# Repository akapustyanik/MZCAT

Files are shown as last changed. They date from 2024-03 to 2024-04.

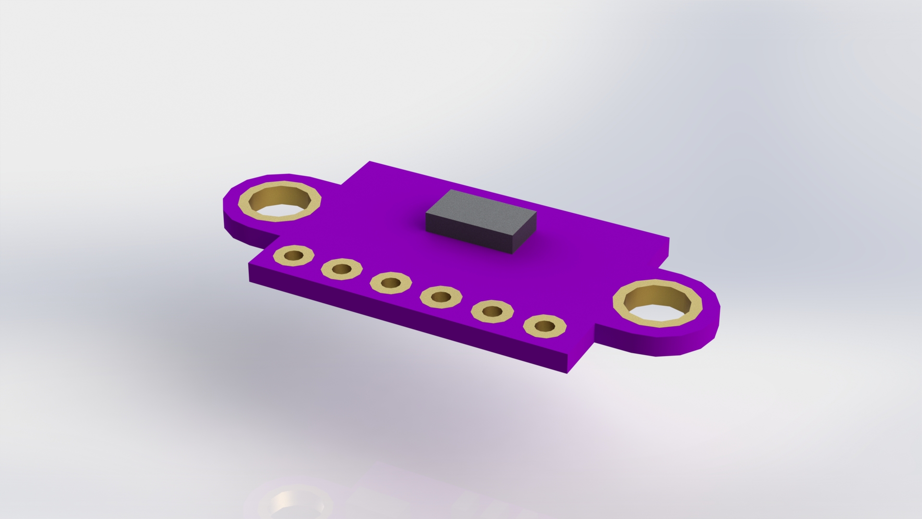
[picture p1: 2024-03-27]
Construction/other_models/vl53l0x/view 3.JPG

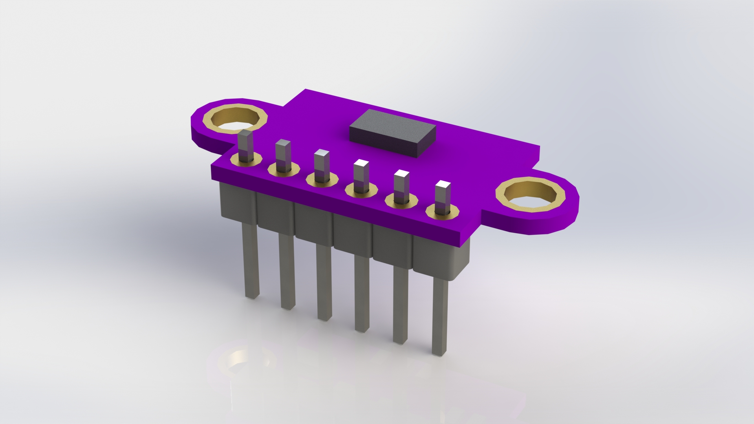
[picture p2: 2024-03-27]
Construction/other_models/vl53l0x/view 1.JPG

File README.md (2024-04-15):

  Создание роботов, находящих и спасающих людей в труднодоступных местах, является актуальной задачей современной робототехники. Роботы-спасатели крайне востребованы, поскольку не всегда есть возможность добраться до места происшествия и начать поиск пострадавших, а компактный робот, который сможет автономно найти пострадавшего и выдать нуждающемуся в помощи спасательный набор, будет полезным и сможет помочь при спасении жизней.

robot photo4

  Я участвую в соревнованиях RoboСup Rescue Maze, поэтому проект, посвящённый теме спасательных роботов актуален для меня.   
Концепцию робота можно сформулировать в трех пунктах:

1) Собственная материнская плата с двумя микроконтроллерами для распределения между ними задач: низкоуровневой - управление ходовой частью и высокоуровневой – считывание значений с датчиков, исполнения алгоритмов перемещения, нахождения кратчайшего пути и поиска пострадавших.
2) Инерциальный модуль собственной разработки с установленным на нём микроконтроллером для фильтрации и обработки данных.
3) Компактная конструкция робота с быстросъёмным механизмом крепления аккумулятора и особое устройство выдачи спасательных наборов со способом загрузки спасательных наборов подобным механизму канцелярского степлера.

В конструкции робота можно выделить основные элементы, а именно:
- Рама и защитная рама, предназначены для обеспечения жёсткости конструкции и закрепления деталей.
- Четыре мотора с уголками для крепления и дисками с шинами.
- Систему выдачи, так же служащей для крепления камер.
- Крепление аккумулятора и сама аккумуляторная сборка.

  Хотелось бы обратить особое внимание на идею создания инерциального модуля собственной разработки. Данный модуль позволит постоянно опрашивать микросхему гироскопа независимо от работы основного алгоритма на основном микроконтроллере, такая система обезопасит от потери выходных данных с датчика и позволит лучше фильтровать данные. Передача данных на основной микроконтроллер может выполняться по любому запрограммированному протоколу, что является большим преимуществом, поскольку можно написать проверку полученных данных и обезопасить алгоритм на основном микроконтроллере от неправильных значений датчика.

  Для инерциального модуля собственной разработки был создан отдельный репозиторий по ссылке - https://github.com/akapustyanik/IMU_Sensor_2023

  Также был создан YouTube канал с примерами работы робота, который можно посмотерть по ссылке - https://www.youtube.com/@mz_cat

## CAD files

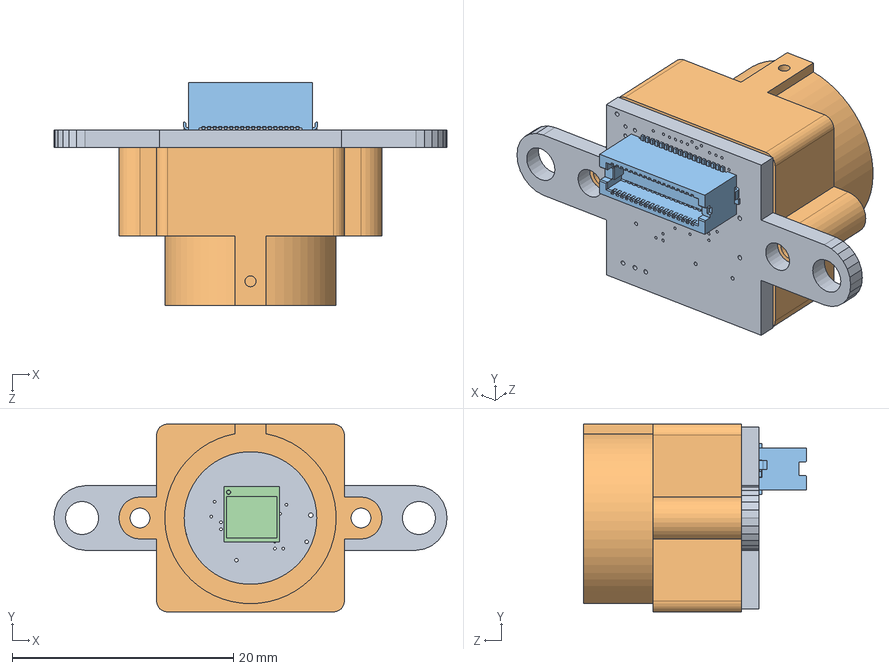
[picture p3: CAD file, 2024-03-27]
Construction/other_models/OpenMV H7/AssemblyModels/openmv4_ov7725.SLDASM
35.6 x 17.0 x 20.2 mm
ov7725
mount_lens
DF1236
CSP2-28

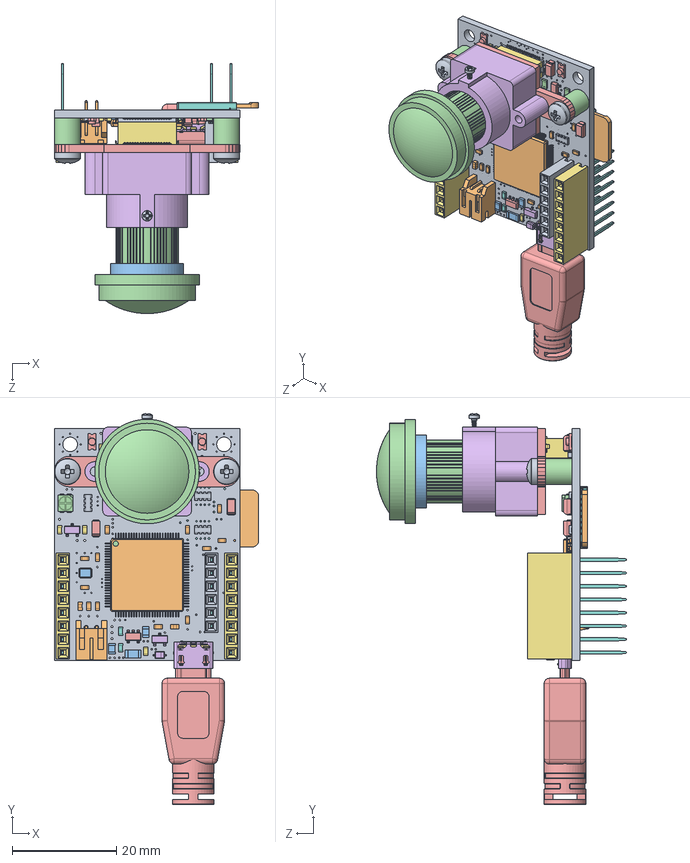
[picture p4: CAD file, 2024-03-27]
Construction/other_models/OpenMV H7/openmv4_h7.SLDASM
39.2 x 74.9 x 47.9 mm
base
C0603K_C0603K x 13
C0805K_C0805K x 2
cap3216h160 x 3
SOD323_BAT54HT1G
960240-6202-AR Body8 x 2
960240-6202-AR Pin Long x 22
960240-6202-AR Body6
Capacitor 0603 x 2
LED SMD RGB
LED 1206 IR x 2
SOT 23 x 2
Resistor 0603 x 5
R0603_SJR x 2
EXBV8V x 3
User Library-LQFP100-3_case
User Library-LQFP100-3_pin x 100
User Library-LQFP100-3_circle
SOT 23-5 x 2
UJ2-MIBH2-4-SMT_01
UJ2-MIBH2-4-SMT_02
1040310811_USD1040310811
DF12-36DS-0.5V
S2B-PH-K-S(LF)(SN)
Crystal-SM2520-4
Standoff metal 5x2.5mm x 2
ov7725
mount_lens
DF1236
CSP2-28
pan head cross recess screw_iso x 3
microsd card
LENS_Standard
LENS_Wide
Micro USB connector

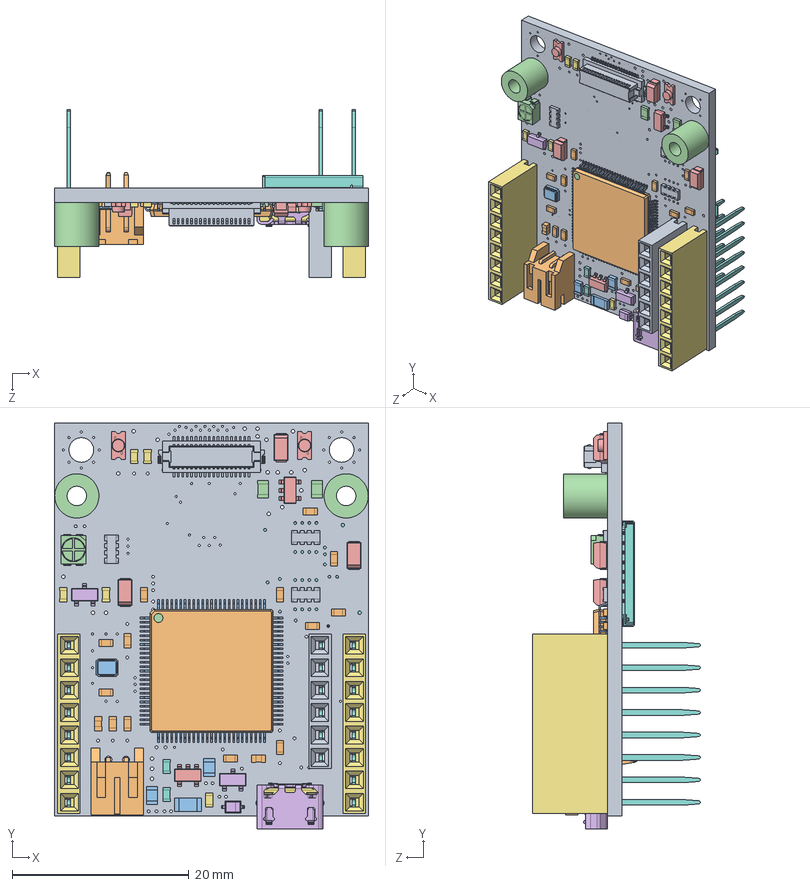
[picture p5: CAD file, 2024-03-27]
Construction/other_models/OpenMV H7/AssemblyModels/openmv4_h7_base.SLDASM
35.6 x 45.9 x 19.0 mm
base
C0603K_C0603K x 13
C0805K_C0805K x 2
cap3216h160 x 3
SOD323_BAT54HT1G
960240-6202-AR Body8 x 2
960240-6202-AR Pin Long x 22
960240-6202-AR Body6
Capacitor 0603 x 2
LED SMD RGB
LED 1206 IR x 2
SOT 23 x 2
Resistor 0603 x 5
R0603_SJR x 2
EXBV8V x 3
User Library-LQFP100-3_case
User Library-LQFP100-3_pin x 100
User Library-LQFP100-3_circle
SOT 23-5 x 2
UJ2-MIBH2-4-SMT_01
UJ2-MIBH2-4-SMT_02
1040310811_USD1040310811
DF12-36DS-0.5V
S2B-PH-K-S(LF)(SN)
Crystal-SM2520-4
Standoff metal 5x2.5mm x 2

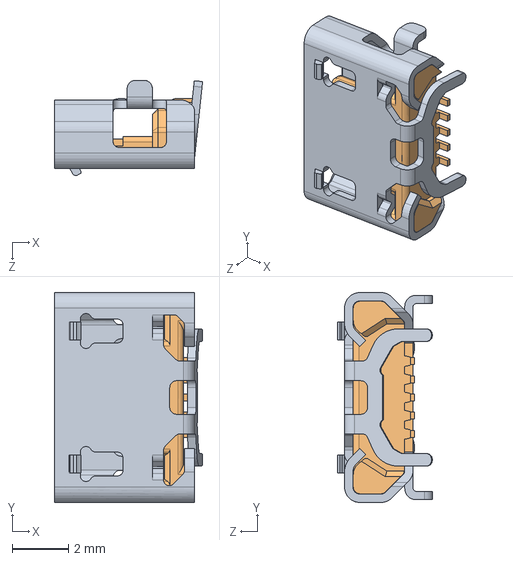
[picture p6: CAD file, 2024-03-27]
Construction/other_models/OpenMV H7/Components/Micro USB socket/UJ2-MIBH2-4-SMT.SLDASM
5.29 x 7.50 x 3.41 mm
UJ2-MIBH2-4-SMT_01
UJ2-MIBH2-4-SMT_02

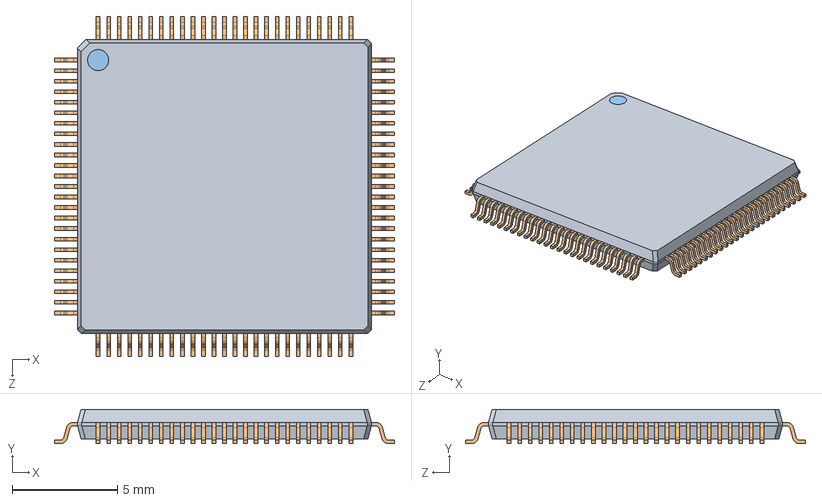
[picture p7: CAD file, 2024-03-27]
Construction/other_models/OpenMV H7/Components/LQFP100/User Library-LQFP100-3.sldasm
16.1 x 1.63 x 16.1 mm
User Library-LQFP100-3_case
User Library-LQFP100-3_pin x 100
User Library-LQFP100-3_circle

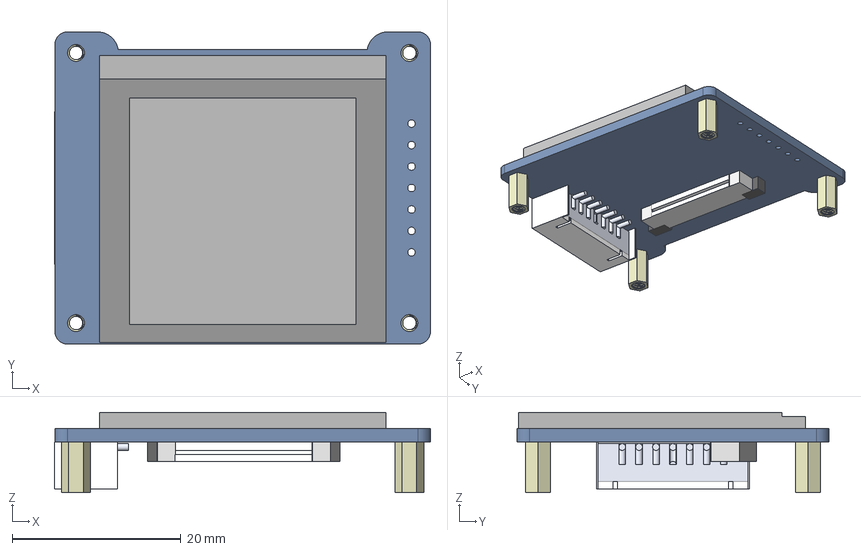
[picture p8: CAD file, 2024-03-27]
Construction/step/1_5inch-rgb-oled-module_asm-1110.stp
44.5 x 37.0 x 9.50 mm
1_5INCH-RGB-OLED
1_5INCH_OLED_RGB_PCBA
M2XH6_COPPER-POST x 4

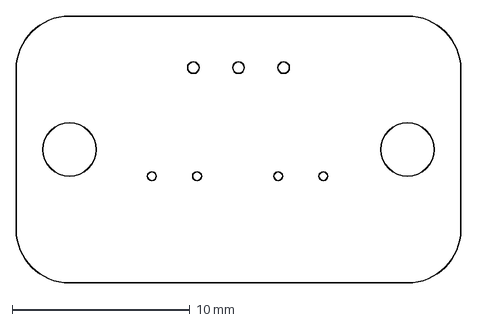
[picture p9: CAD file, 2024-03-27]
Construction/dxf/osvesh.dxf
25.0 x 15.0 mm

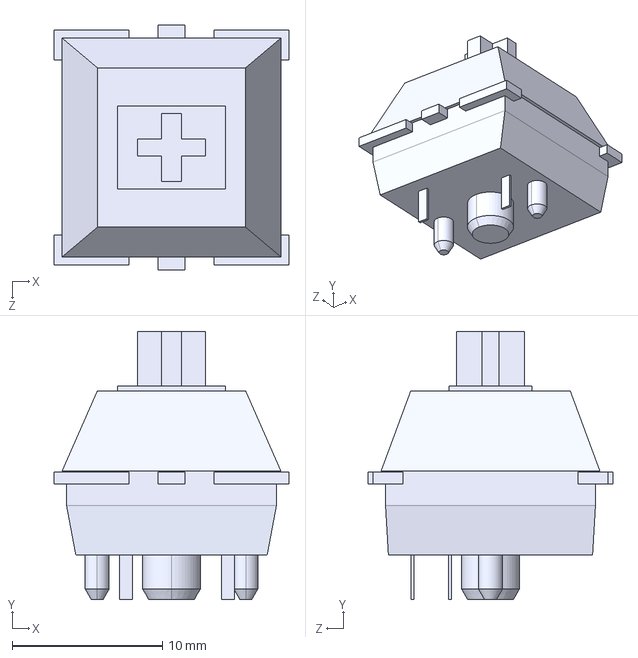
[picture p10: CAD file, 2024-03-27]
Construction/other_models/cherrry red/cherry mx.STEP
15.6 x 17.9 x 16.3 mm

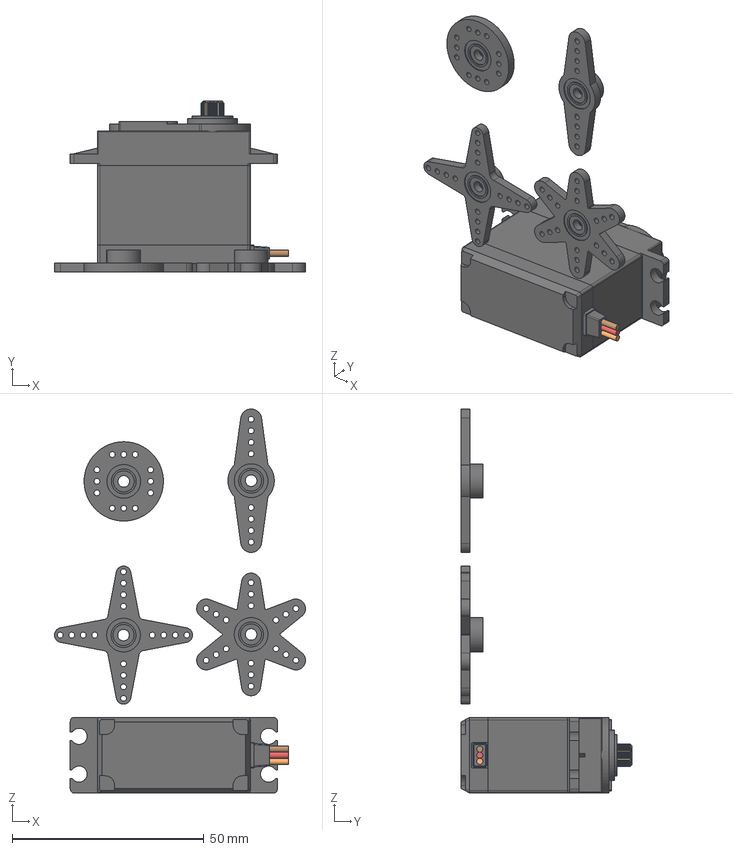
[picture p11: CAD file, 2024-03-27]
Construction/other_models/MG996R/Servo Motor MG996R_ 一字摇臂.step
65.4 x 44.5 x 100.1 mm

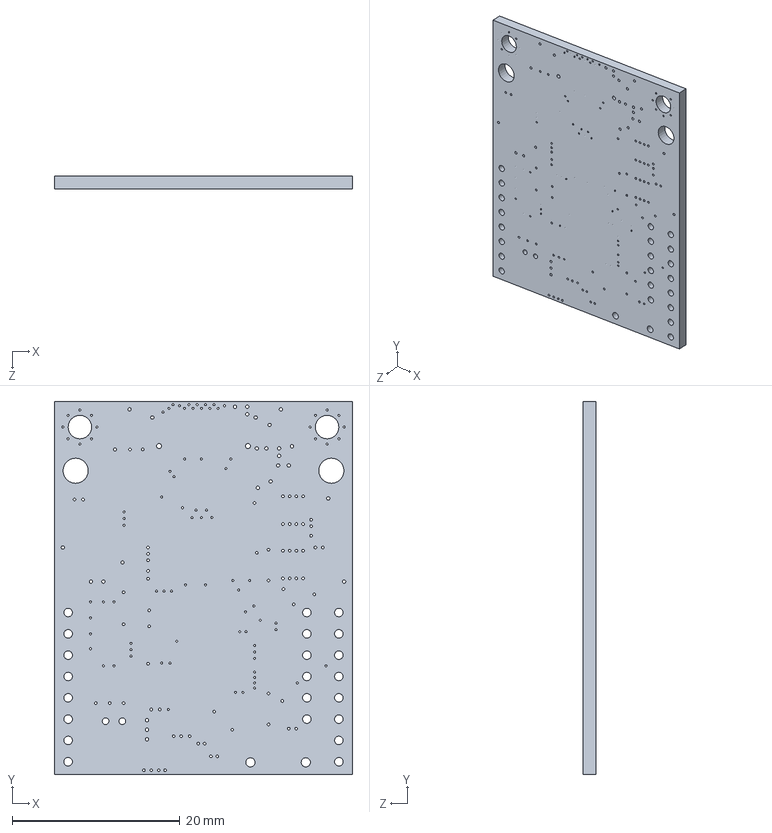
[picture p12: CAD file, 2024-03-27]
Construction/other_models/OpenMV H7/Boards/base.sldprt
35.6 x 44.5 x 1.60 mm

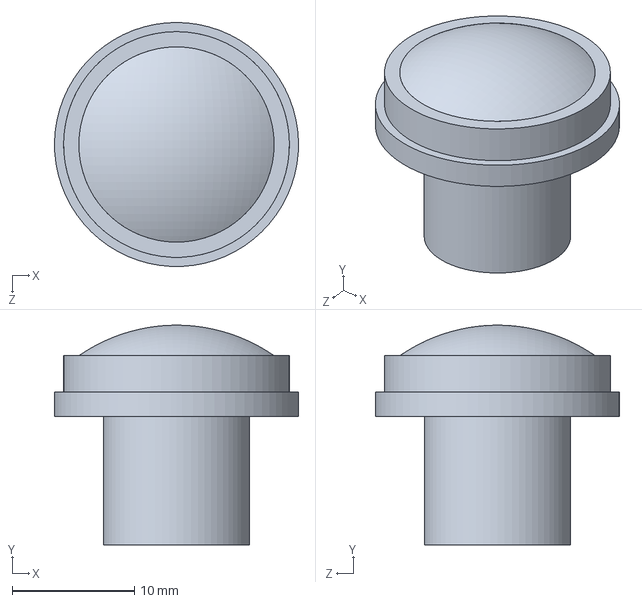
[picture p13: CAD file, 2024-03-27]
Construction/other_models/OpenMV H7/Components/Camera_20mm/LENS_Wide.SLDPRT
20.0 x 18.0 x 20.0 mm

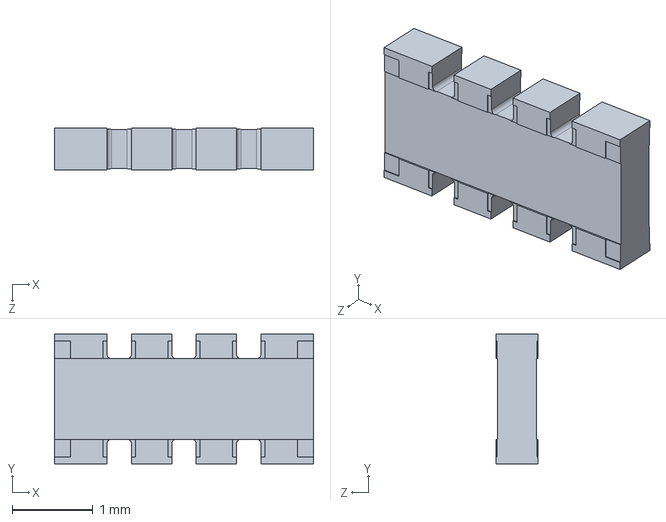
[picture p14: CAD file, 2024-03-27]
Construction/other_models/OpenMV H7/Components/EXB/EXBV8V.SLDPRT
3.20 x 1.60 x 0.52 mm

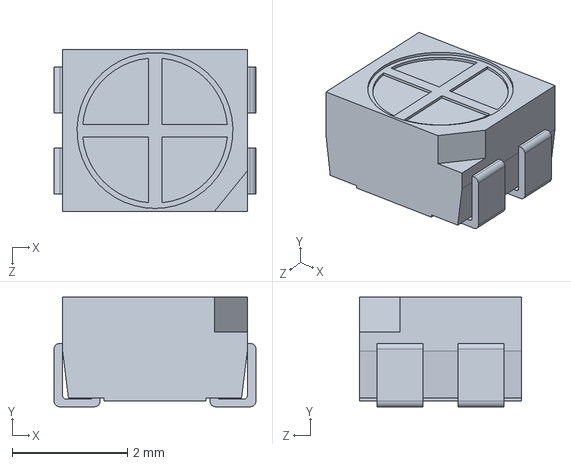
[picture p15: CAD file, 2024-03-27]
Construction/other_models/OpenMV H7/Components/LED SMD RGB.SLDPRT
3.50 x 1.90 x 2.80 mm

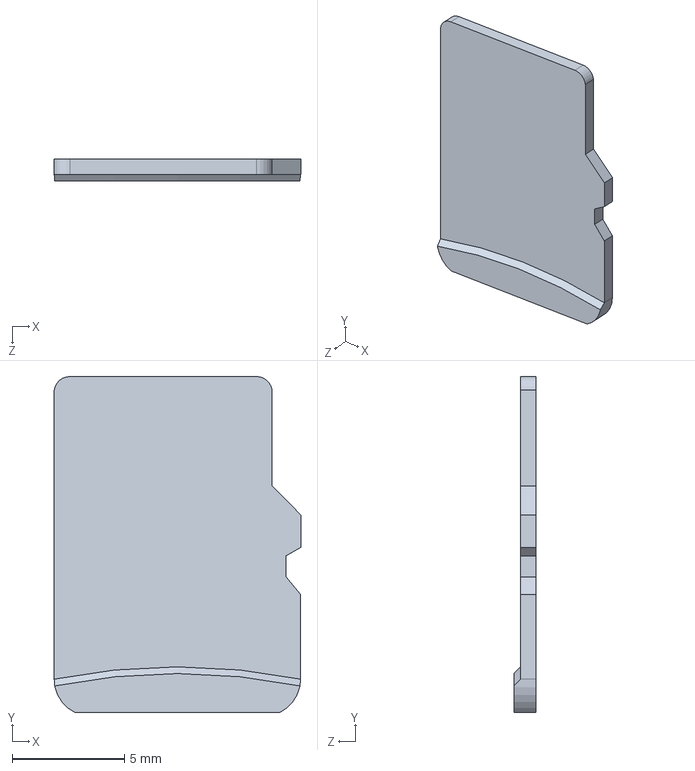
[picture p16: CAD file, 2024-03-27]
Construction/other_models/OpenMV H7/Components/Micro SD card/microsd card.SLDPRT
11.0 x 15.0 x 1.00 mm

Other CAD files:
Construction/dwg/raw dwg.dwg
Construction/other_models/OpenMV H7/Components/LQFP100/User Library-LQFP100-3_pin.sldprt
Construction/other_models/OpenMV H7/Components/Micro USB socket/UJ2-MIBH2-4-SMT_02.SLDPRT
Construction/other_models/OpenMV H7/Components/standoffs/Standoff metal 5x2.5mm.SLDPRT
Construction/dwg/osvesh.dwg
Construction/dwg/raw.dwg
Construction/dxf/akkum_frame.dxf
Construction/dxf/frame.dxf
Construction/dxf/holder.dxf
Construction/dxf/led_5mm.dxf
Construction/dxf/maze_04.dxf
Construction/dxf/maze_4.dxf
Construction/dxf/motherboard_countour.dxf
Construction/dxf/motherboard_countour2.dxf
Construction/dxf/motherboard_countour3.dxf
Construction/dxf/osvesh2.dxf
Construction/dxf/osvesh3.dxf
Construction/dxf/osvesh4.dxf
Construction/dxf/osvesh5.dxf
Construction/dxf/protection.dxf
Construction/dxf/protection_frame.dxf
Construction/dxf/protection_frame2.dxf
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

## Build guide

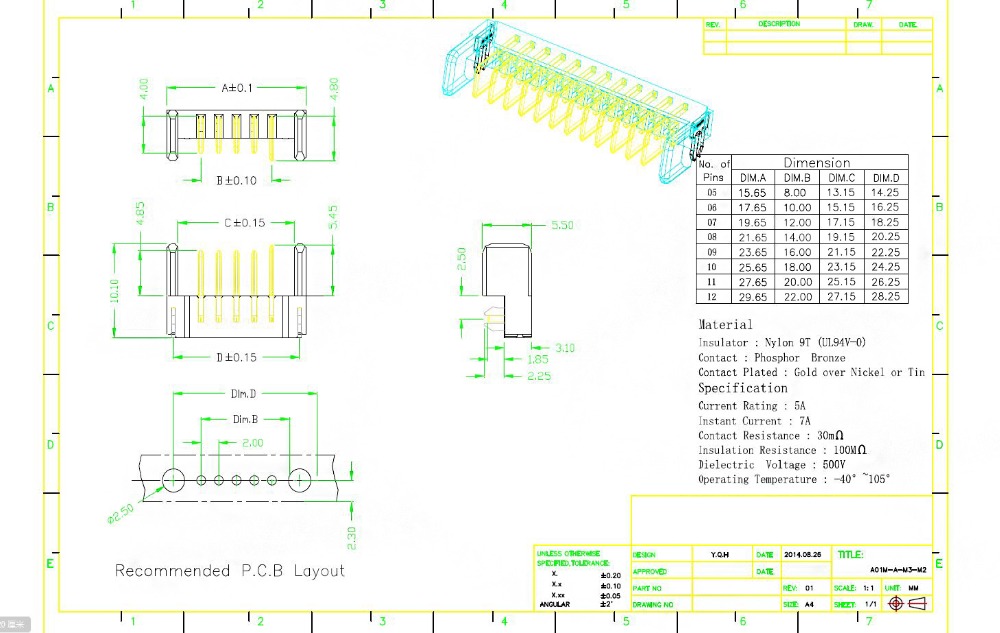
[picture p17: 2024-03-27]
Construction/drawings_datasheet/разъём аккум. 2.jpg

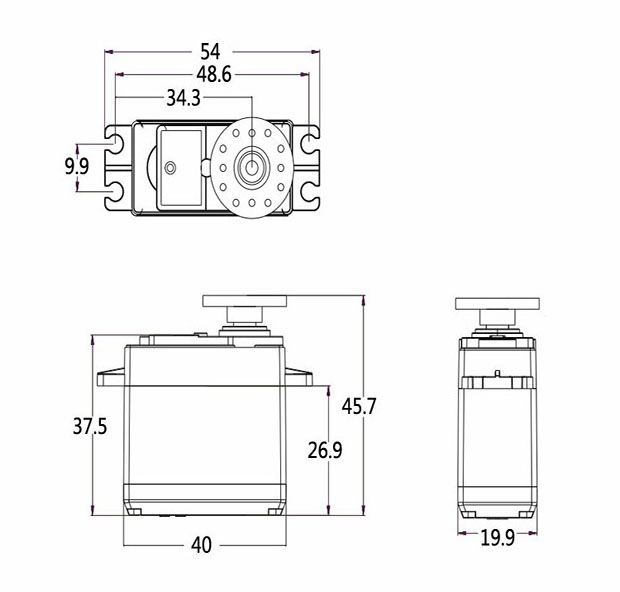
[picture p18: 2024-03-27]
Construction/other_models/MG996R/Main reference.jpg

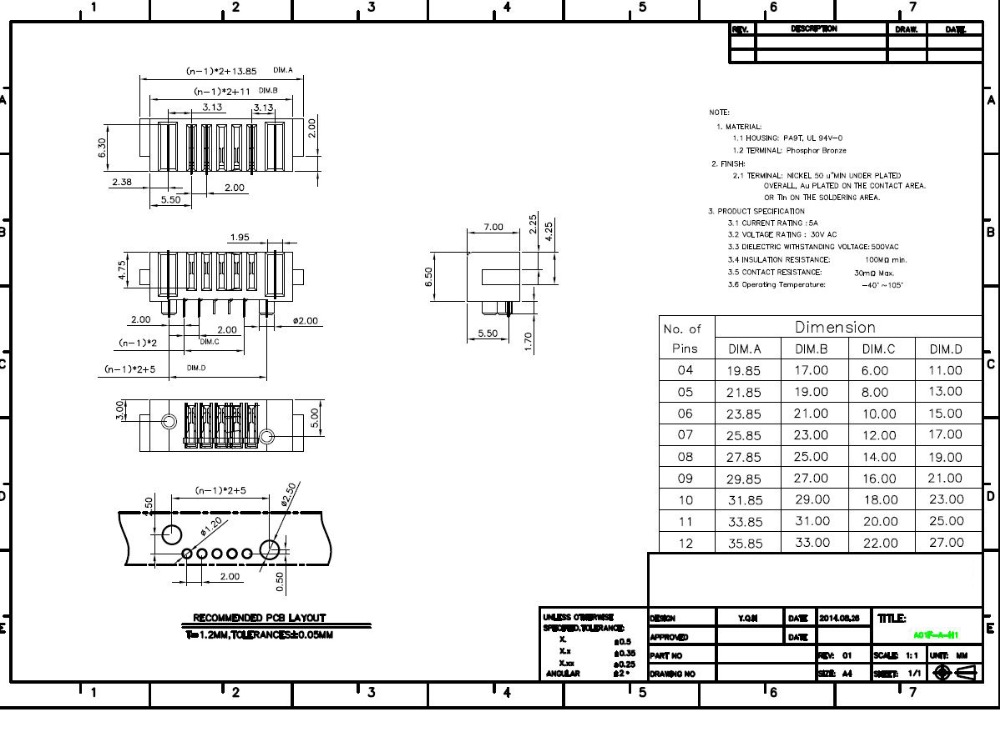
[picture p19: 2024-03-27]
Construction/drawings_datasheet/разъём аккум..jpg

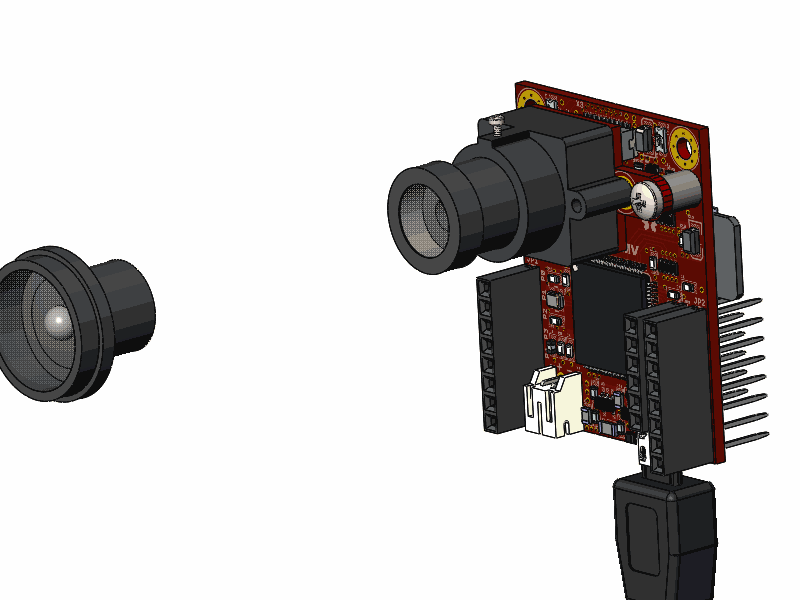
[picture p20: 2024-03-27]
Construction/other_models/OpenMV H7/Animation.gif

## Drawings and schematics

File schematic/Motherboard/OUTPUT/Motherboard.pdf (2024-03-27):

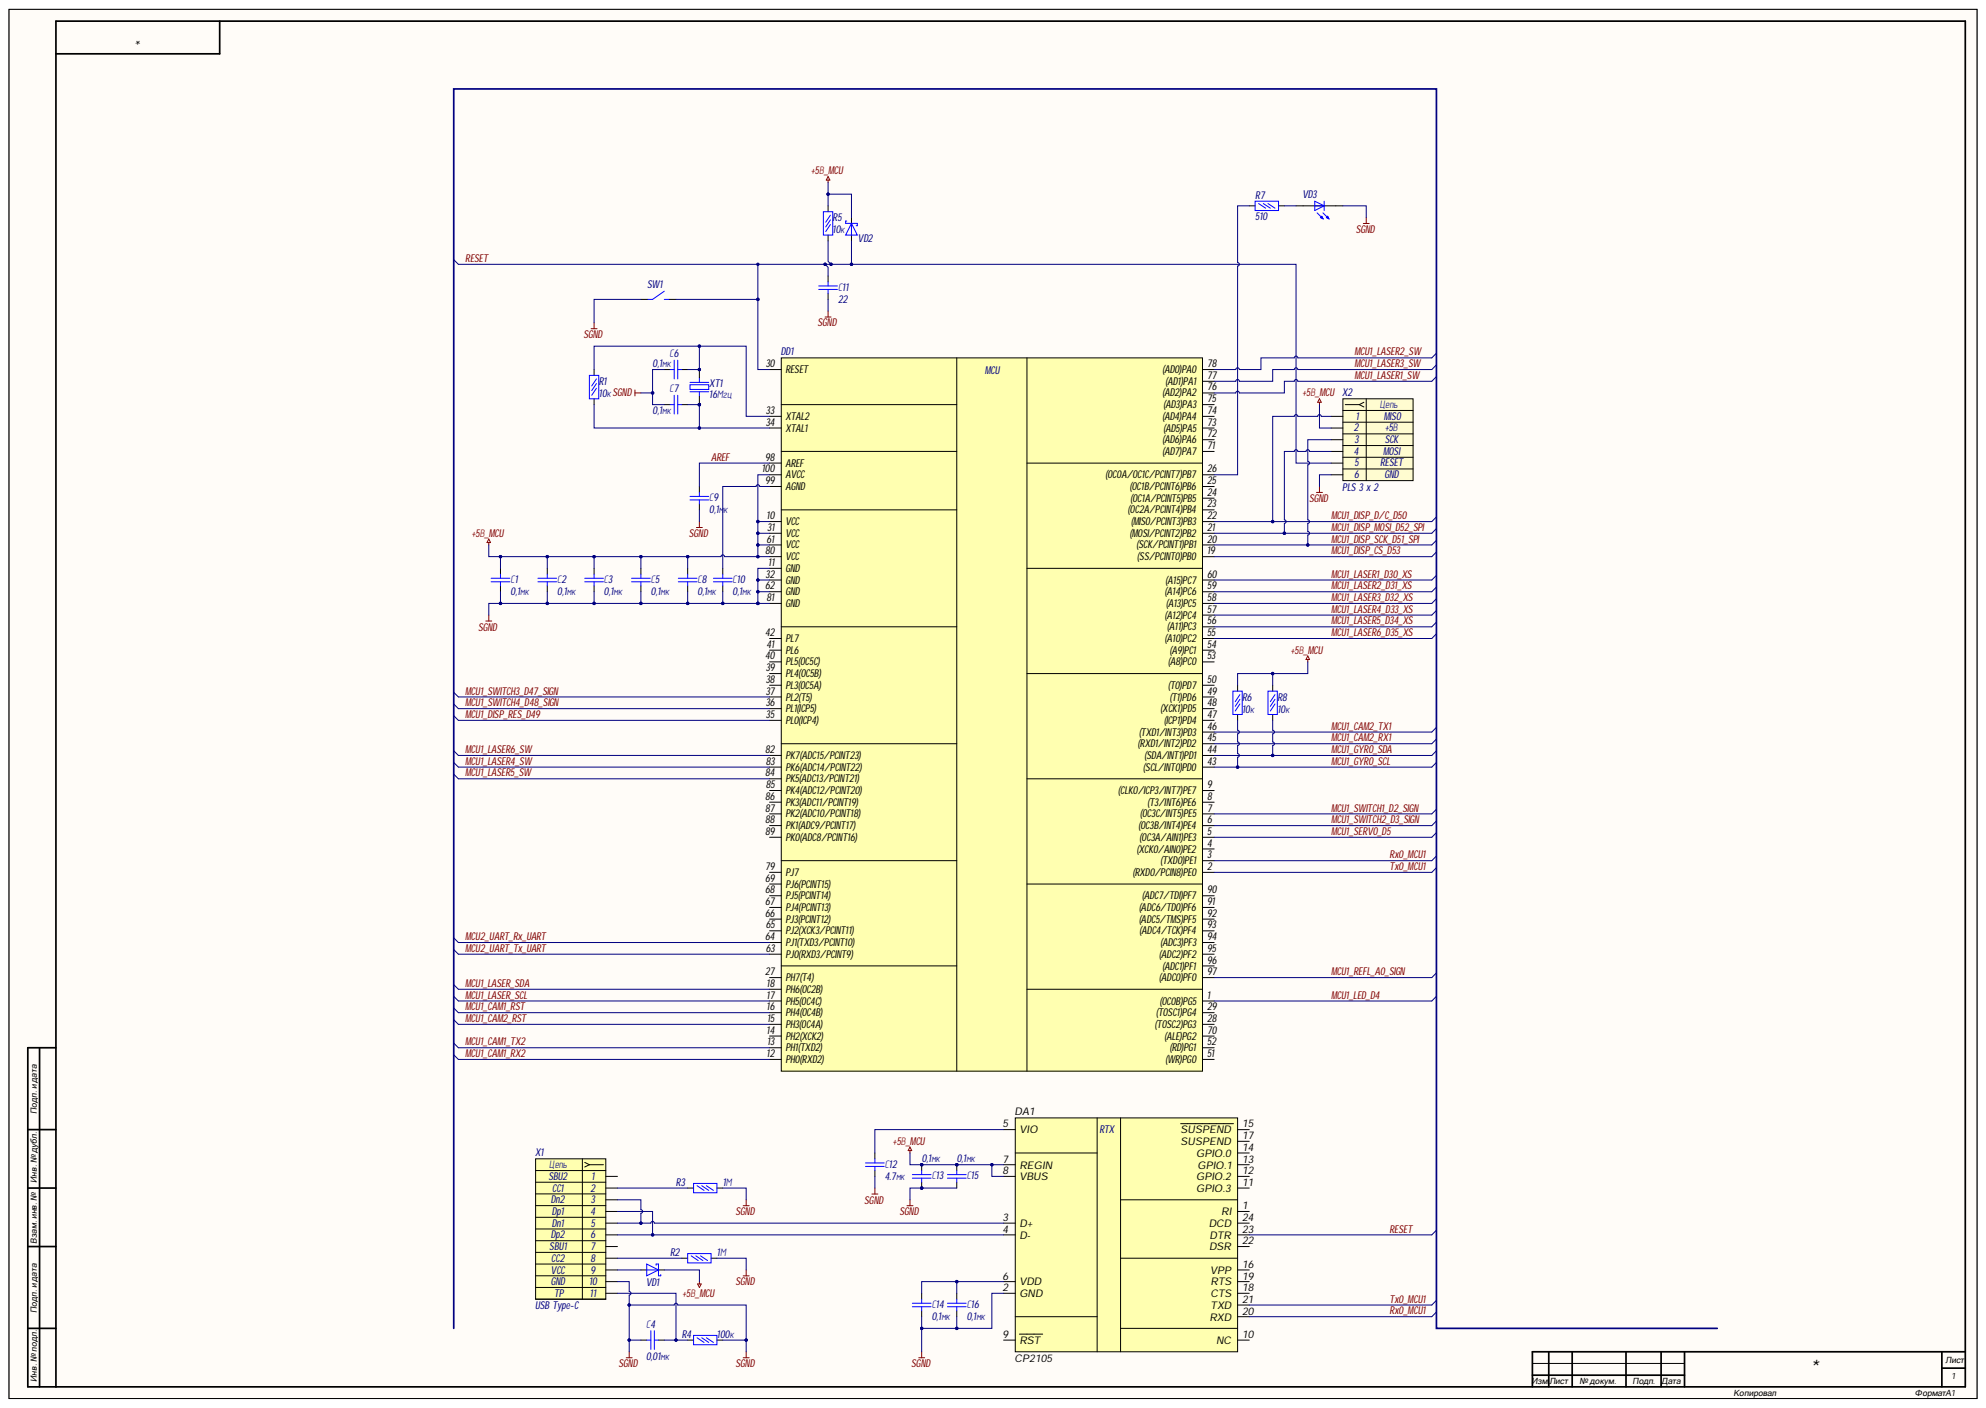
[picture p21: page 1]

AVCC 100 | +5В_MCU | 6 | GND

MCU2_UART_Rx_UART | PK4(ADC12/PCINT20) 85 | (RXD0/PCIN8)PE0

PK2(ADC10/PCINT18) 87 | | 4 (OC3A/AIN1)PE3 5 (OC3B/INT4)PE4 6 (OC3C/INT5)PE5 7 (T3/INT6)PE6 8 (CLKO/ICP3/INT7)PE7 2 (TXD0)PE1 3 (XCK0/AIN0)PE2 9

* Инв. № подл. Инв. № дубл. Подп. и дата Взам. инв. № Подп. и дата

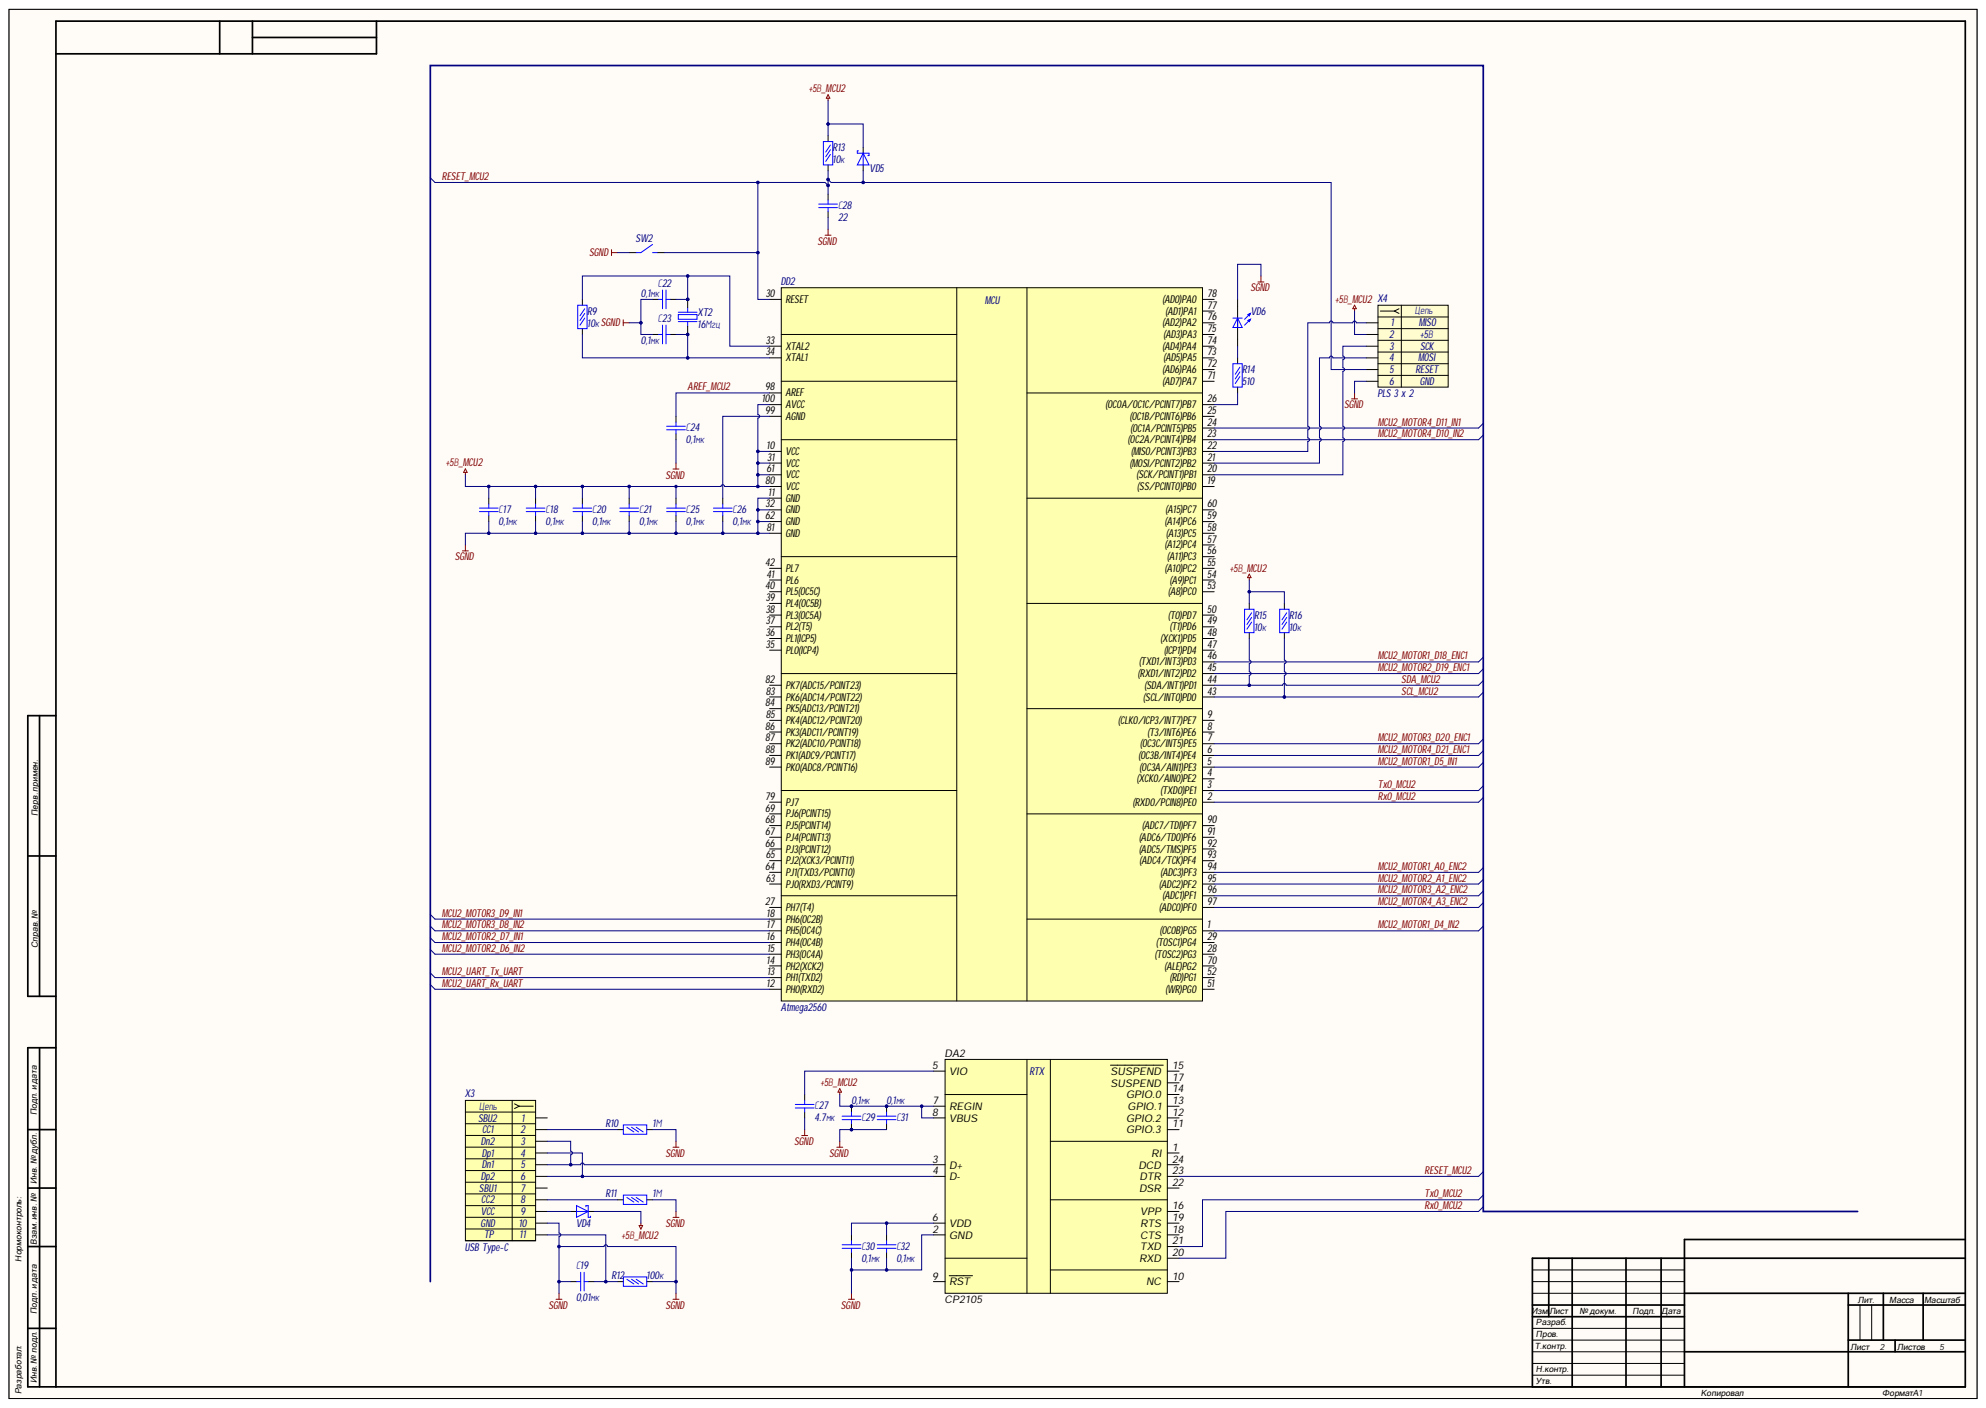
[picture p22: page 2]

RESET 30 | MCU

1 | MISO
2 | +5В

PK7(ADC15/PCINT23) 82 | | SDA_MCU2
PK6(ADC14/PCINT22) 83 | | SCL_MCU2
PK5(ADC13/PCINT21) 84 | MCU2_MOTOR3_D20_ENC1
PK4(ADC12/PCINT20) 85 | (RXD0/PCIN8)PE0
PK2(ADC10/PCINT18) 87 | | 2 (TXD0)PE1 7 (T3/INT6)PE6 8 (CLKO/ICP3/INT7)PE7 9 3 (XCK0/AIN0)PE2 4 (OC3A/AIN1)PE3 5 (OC3B/INT4)PE4 6 (OC3C/INT5)PE5

PK1(ADC9/PCINT17) 88 | MCU2_MOTOR4_D21_ENC1
PK0(ADC8/PCINT16) 89 | MCU2_MOTOR1_D5_IN1

Инв. № подл. Инв. № дубл. Подп. и дата Взам. инв. № Подп. и дата Перв. примен. Справ.№

PJ7 79 | Rx0_MCU2
PJ6(PCINT15) 69 | MCU2_MOTOR1_A0_ENC2
PJ5(PCINT14) 68 | (ADC0)PF0
PJ3(PCINT12) 66 | | 97 (ADC1)PF1 96 (ADC2)PF2 92 (ADC6/TDO)PF6 91 (ADC7/TDI)PF7 90 95 (ADC3)PF3 94 (ADC4/TCK)PF4 93 (ADC5/TMS)PF5

PH7(T4) 27 | MCU2_MOTOR4_A3_ENC2
PH6(OC2B) 18 | MCU2_MOTOR1_D4_IN2

Изм. | Лист | № докум. | Подп. | Дата
Разраб.
Пров.
Т.контр. | | | | | Лист 2 | Листов 5

Н.контр.
Утв.

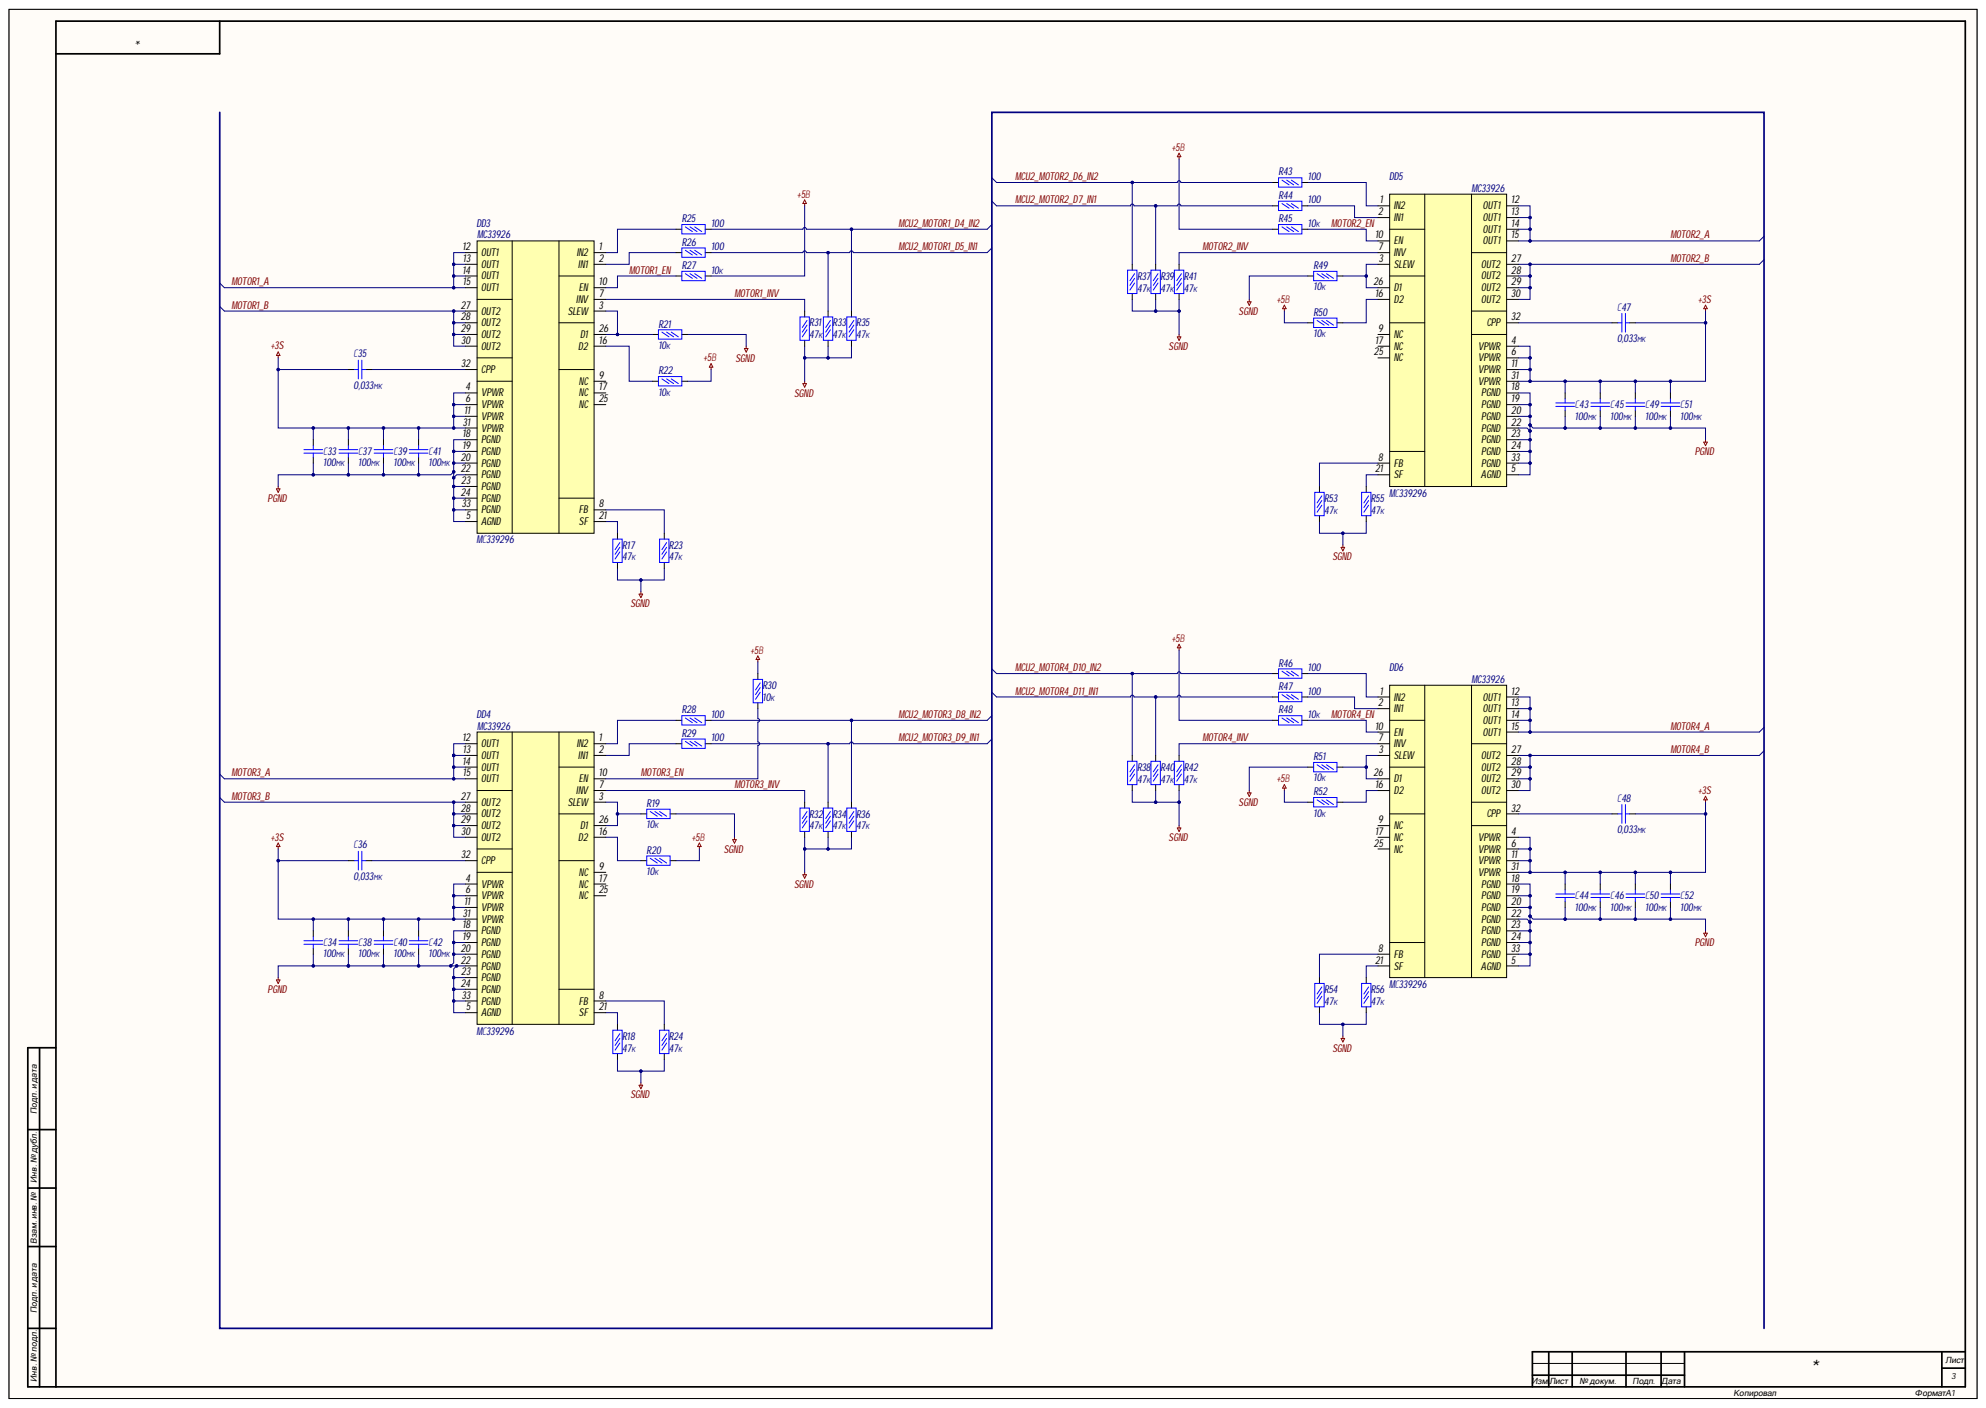
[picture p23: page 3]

С36 | OUT2 28 | R19

Инв. № подл. Инв. № дубл. Подп. и дата Взам. инв. № Подп. и дата

* | Лист 3

Изм | .Лист | № докум . | П одп . | Дата

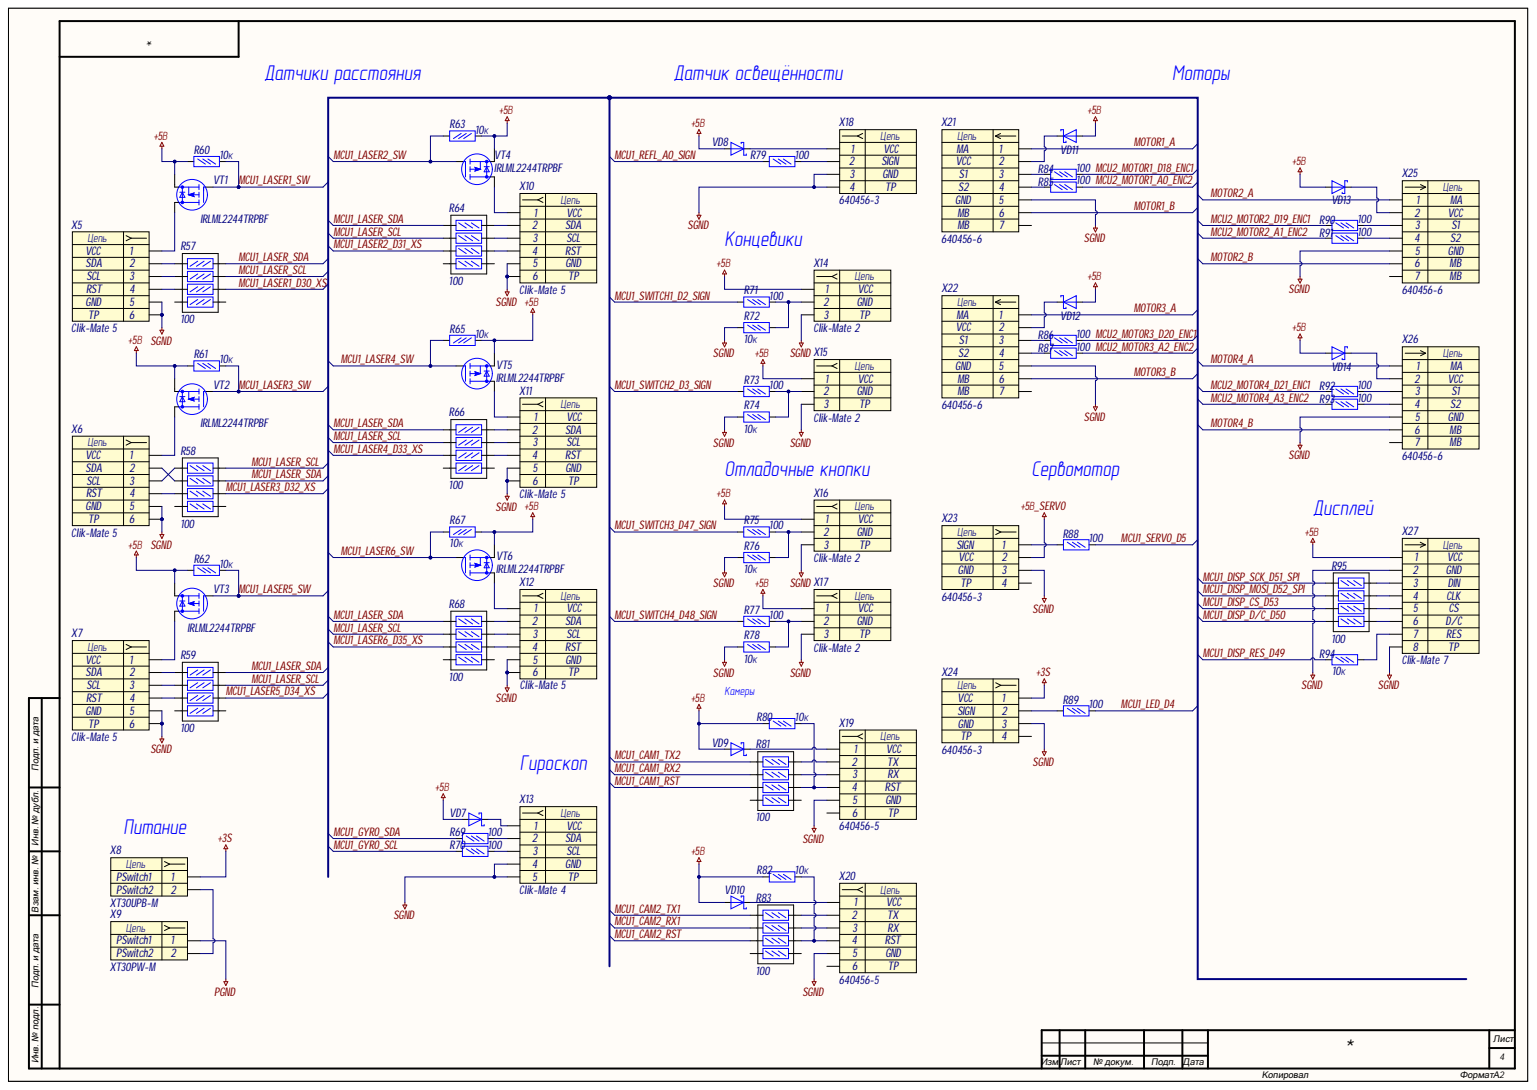
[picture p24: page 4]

* Инв. № подл. Инв. № дубл. Подп. и дата Взам. инв. № Подп. и дата

1 | VCC
2 | TX
3 | RX
4 | RST
5 | GND

2 | SDA
3 | SCL

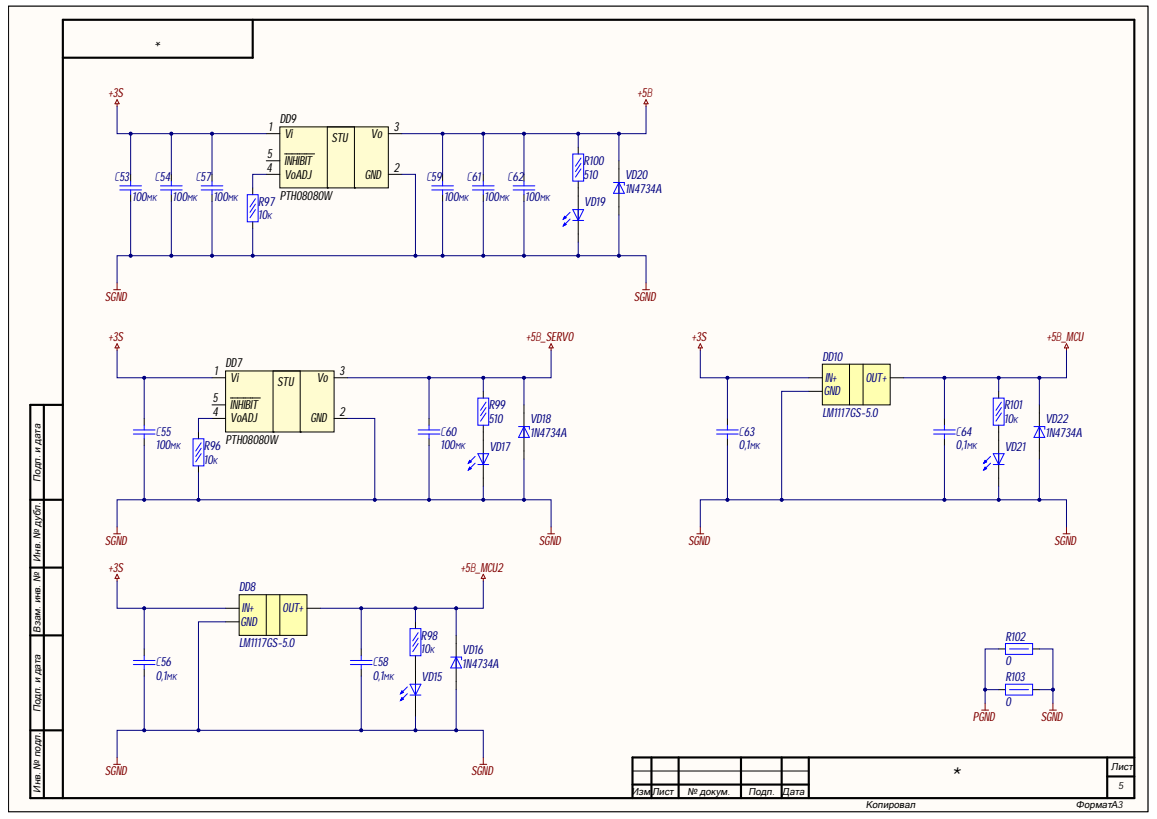
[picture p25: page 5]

Vi 1 | STU

IN+ GND | OUT+

дубл. Подп. и дата Взам. инв. №

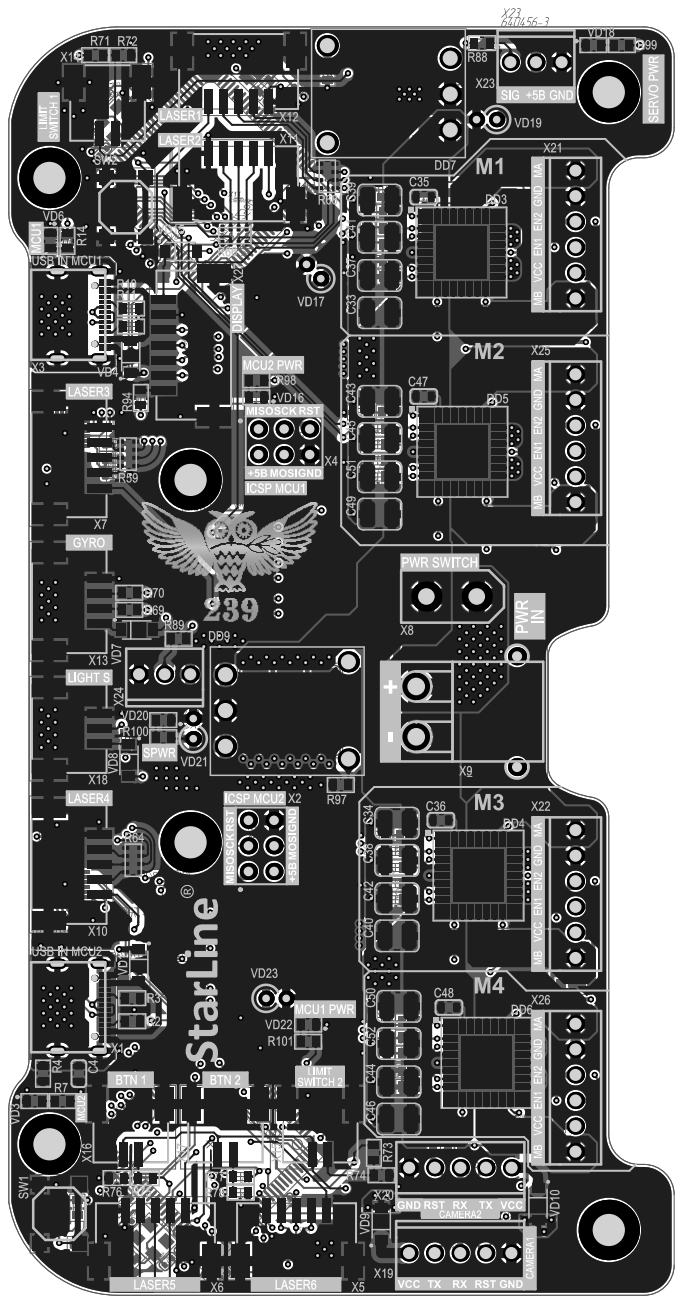
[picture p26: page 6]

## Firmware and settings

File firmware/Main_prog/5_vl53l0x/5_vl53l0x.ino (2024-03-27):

#include "Adafruit_VL53L0X.h"

// address we will assign if dual sensor is present
#define LOX1_ADDRESS 0x01
#define LOX2_ADDRESS 0x02
#define LOX3_ADDRESS 0x03
#define LOX4_ADDRESS 0x04
#define LOX5_ADDRESS 0x05
#define LOX6_ADDRESS 0x06

// set the pins to shutdown
#define SHT_LOX1 31//31
#define SHT_LOX2 34//34
#define SHT_LOX3 33//33
#define SHT_LOX4 30//30
#define SHT_LOX5 35//35
#define SHT_LOX6 32//32

#define MOSFET1 22
#define MOSFET2 23
#define MOSFET3 24
#define MOSFET4 A13
#define MOSFET5 A14
#define MOSFET6 A15

// objects for the vl53l0x
Adafruit_VL53L0X lox1 = Adafruit_VL53L0X();
Adafruit_VL53L0X lox2 = Adafruit_VL53L0X();
Adafruit_VL53L0X lox3 = Adafruit_VL53L0X();
Adafruit_VL53L0X lox4 = Adafruit_VL53L0X();
Adafruit_VL53L0X lox5 = Adafruit_VL53L0X();
Adafruit_VL53L0X lox6 = Adafruit_VL53L0X();

// this holds the measurement
VL53L0X_RangingMeasurementData_t measure1;
VL53L0X_RangingMeasurementData_t measure2;
VL53L0X_RangingMeasurementData_t measure3;
VL53L0X_RangingMeasurementData_t measure4;
VL53L0X_RangingMeasurementData_t measure5;
VL53L0X_RangingMeasurementData_t measure6;

/*
    Reset all sensors by setting all of their XSHUT pins low for delay(10), then set all XSHUT high to bring out of reset
    Keep sensor #1 awake by keeping XSHUT pin high
    Put all other sensors into shutdown by pulling XSHUT pins low
    Initialize sensor #1 with lox.begin(new_i2c_address) Pick any number but 0x29 and it must be under 0x7F. Going with 0x30 to 0x3F is probably OK.
    Keep sensor #1 awake, and now bring sensor #2 out of reset by setting its XSHUT pin high.
    Initialize sensor #2 with lox.begin(new_i2c_address) Pick any number but 0x29 and whatever you set the first sensor to
 */
void setID() {
  // all reset
  digitalWrite(SHT_LOX1, LOW);    
  digitalWrite(SHT_LOX2, LOW);
  digitalWrite(SHT_LOX3, LOW);
  digitalWrite(SHT_LOX4, LOW);
  digitalWrite(SHT_LOX5, LOW);
  digitalWrite(SHT_LOX6, LOW);
  delay(10);
  // all unreset
  digitalWrite(SHT_LOX1, HIGH);
  digitalWrite(SHT_LOX2, HIGH);
  digitalWrite(SHT_LOX3, HIGH);
  digitalWrite(SHT_LOX4, HIGH);
  digitalWrite(SHT_LOX5, HIGH);
  digitalWrite(SHT_LOX6, HIGH);
  delay(10);

  // activating LOX1 and resetting LOX2
  digitalWrite(SHT_LOX1, HIGH);
  digitalWrite(SHT_LOX2, LOW);
  digitalWrite(SHT_LOX3, LOW);
  digitalWrite(SHT_LOX4, LOW);
  digitalWrite(SHT_LOX5, LOW);
  digitalWrite(SHT_LOX6, LOW);

  // initing LOX1
  if(!lox1.begin(LOX1_ADDRESS)) {
    Serial.println(F("Failed to boot 1 VL53L0X"));
    while(1);
  }
  delay(10);

  // activating LOX2
  digitalWrite(SHT_LOX2, HIGH);
  delay(10);

  //initing LOX2
  if(!lox2.begin(LOX2_ADDRESS)) {
    Serial.println(F("Failed to boot 2 VL53L0X"));
    while(1);
  }

  digitalWrite(SHT_LOX3, HIGH);
  delay(10);

  //initing LOX2
  if(!lox3.begin(LOX3_ADDRESS)) {
    Serial.println(F("Failed to boot 3 VL53L0X"));
    while(1);
  }

  digitalWrite(SHT_LOX4, HIGH);
  delay(10);

  //initing LOX2
  if(!lox4.begin(LOX4_ADDRESS)) {
    Serial.println(F("Failed to boot 4 VL53L0X"));
    while(1);
  }

  digitalWrite(SHT_LOX5, HIGH);
  delay(10);

  //initing LOX2
  if(!lox5.begin(LOX5_ADDRESS)) {
    Serial.println(F("Failed to boot 5 VL53L0X"));
    while(1);
  }

  digitalWrite(SHT_LOX6, HIGH);
  delay(10);

  //initing LOX2
  if(!lox6.begin(LOX6_ADDRESS)) {
    Serial.println(F("Failed to boot 6 VL53L0X"));
    //while(1);
  }
}

void read_sensors() {
  
  lox1.rangingTest(&measure1, false); // pass in 'true' to get debug data printout!
  lox2.rangingTest(&measure2, false); // pass in 'true' to get debug data printout!
  lox3.rangingTest(&measure3, false);
  lox4.rangingTest(&measure4, false);
  lox5.rangingTest(&measure5, false);
  lox6.rangingTest(&measure6, false);
  
  // print sensor one reading
  Serial.print(F("1: "));
  if(measure1.RangeStatus != 4) {     // if not out of range
    Serial.print(measure1.RangeMilliMeter);
  } else {
    Serial.print(F("Out of range"));
  }
  
  Serial.print(F(" "));

  // print sensor two reading
  Serial.print(F("2: "));
  if(measure2.RangeStatus != 4) {
    Serial.print(measure2.RangeMilliMeter);
  } else {
    Serial.print(F("Out of range"));
  }

  Serial.print(F(" "));

  // print sensor two reading
  Serial.print(F("3: "));
  if(measure3.RangeStatus != 4) {
    Serial.print(measure3.RangeMilliMeter);
  } else {
    Serial.print(F("Out of range"));
  }

  Serial.print(F(" "));

  // print sensor two reading
  Serial.print(F("4: "));
  if(measure4.RangeStatus != 4) {
    Serial.print(measure4.RangeMilliMeter);
  } else {
    Serial.print(F("Out of range"));
  }

  Serial.print(F(" "));

  // print sensor two reading
  Serial.print(F("5: "));
  if(measure5.RangeStatus != 4) {
    Serial.print(measure5.RangeMilliMeter);
  } else {
    Serial.print(F("Out of range"));
  }

  Serial.print(F(" "));

  // print sensor two reading
  Serial.print(F("6: "));
  if(measure6.RangeStatus != 4) {
    Serial.print(measure6.RangeMilliMeter);
  } else {
    Serial.print(F("Out of range"));
  }
  
  Serial.println();
}

void setup() {
  Serial.begin(115200);
  pinMode(MOSFET1, OUTPUT);
  pinMode(MOSFET2, OUTPUT);
  pinMode(MOSFET3, OUTPUT);
  pinMode(MOSFET4, OUTPUT);
  pinMode(MOSFET5, OUTPUT);
  pinMode(MOSFET6, OUTPUT);
  digitalWrite(MOSFET1, LOW);
  digitalWrite(MOSFET2, LOW);
  digitalWrite(MOSFET3, LOW);
  digitalWrite(MOSFET4, LOW);
  digitalWrite(MOSFET5, LOW);
  digitalWrite(MOSFET6, LOW);
  // wait until serial port opens for native USB devices
  while (! Serial) { delay(1); }

  pinMode(SHT_LOX1, OUTPUT);
  pinMode(SHT_LOX2, OUTPUT);
  pinMode(SHT_LOX3, OUTPUT);
  pinMode(SHT_LOX4, OUTPUT);
  pinMode(SHT_LOX5, OUTPUT);

  Serial.println(F("Shutdown pins inited..."));

  digitalWrite(SHT_LOX1, LOW);
  digitalWrite(SHT_LOX2, LOW);
  digitalWrite(SHT_LOX3, LOW);
  digitalWrite(SHT_LOX4, LOW);
  digitalWrite(SHT_LOX5, LOW);

  Serial.println(F("Both in reset mode...(pins are low)"));
  
  
  Serial.println(F("Starting..."));
  setID();
}

void loop() {
  read_sensors();
  delay(1);
}

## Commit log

2024-03-27 new repository
    add new repository MZCAT
    [0805.SLDPRT, 0805.ipt, 1040310811_USD1040310811.sldprt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]
2024-04-15 modified readme
    modified readme
    [0805.SLDPRT, 0805.ipt, 1040310811_USD1040310811.sldprt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]
2025-04-03 рабочий код добавлен
